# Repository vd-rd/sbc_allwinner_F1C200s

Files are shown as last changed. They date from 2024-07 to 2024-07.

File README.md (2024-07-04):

# Allwinner F1C200s SBC

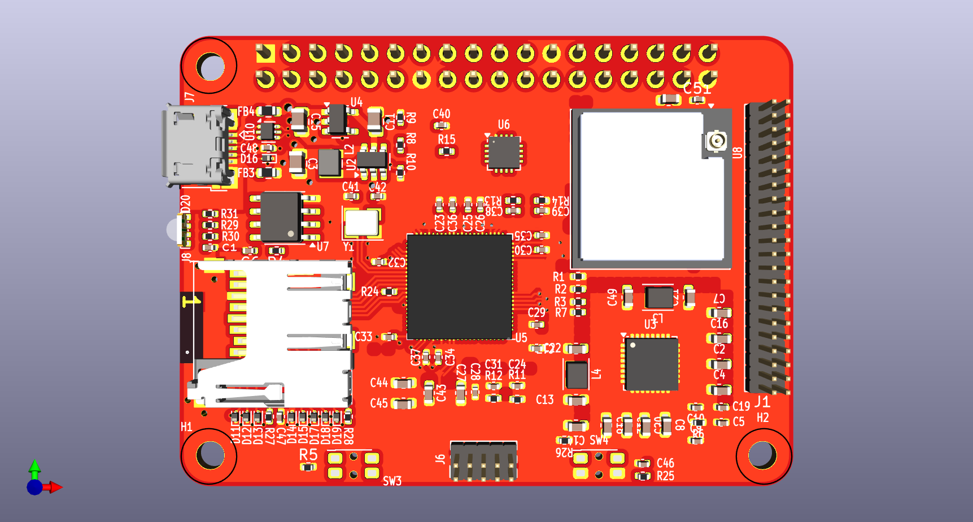
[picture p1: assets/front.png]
board_render


This board embeds a SIP (single core 533MHz ARM926EJ-S with 64MB DDR) with AXP173 PMIC, IO headers and microSD/eMMC storage. The board is also compatible with the smaller F1C100s that only embedds 32MB DDR RAM.

Note: The uC has two SDIO controllers (SDIO0 - 4bit wide, SDIO1 - 1bit wide). SDIO0 is used for SDCard. To provide wireless networking, while not sacrificing a large amount of pins, a design decision was made to use ESP32 module to provide WiFi/BT capabilities connected via SPI bus, leveraging [ESP_HOSTED_NG](https://github.com/espressif/esp-hosted) as a solution.
## Board overview (draft):

[TBD]

## Board features

| Characteristic | Description |
| --- | --- |
| Dimensions | 60mm x 40mm |
| Processor | Allwinner F1C100s/F1C200s ARM926EJ-S @533MHz |
| Oscillators | 24MHz main clock |
| RAM | 32/64MB embedded DDR memory |
| Storage | microSD/eMMC |
| USB | 1 microUSB OTG |
| Supply | Power path between USB/Vin/Battery, 5V max |

## Notes and observations
[TBD]

## Resources
 - online viewer for schematic/layout (https://cadlab.io/project/23988).

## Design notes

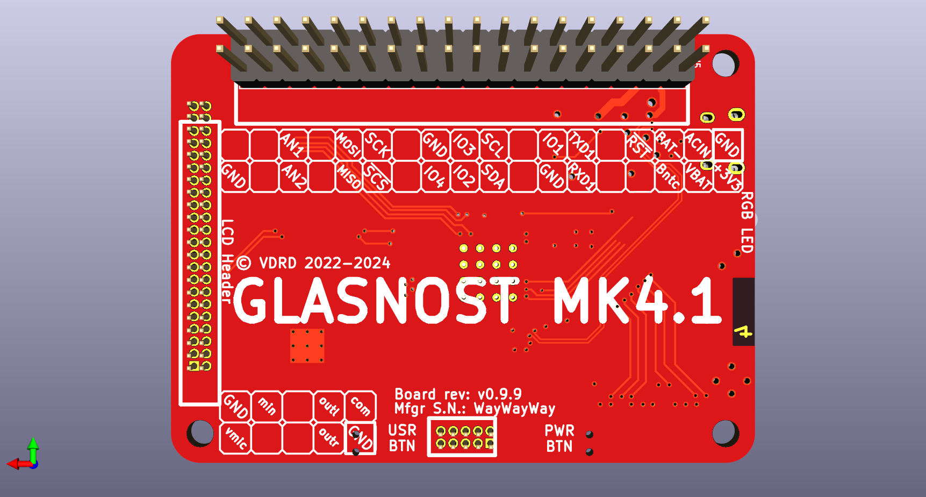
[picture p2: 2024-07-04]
assets/back.png

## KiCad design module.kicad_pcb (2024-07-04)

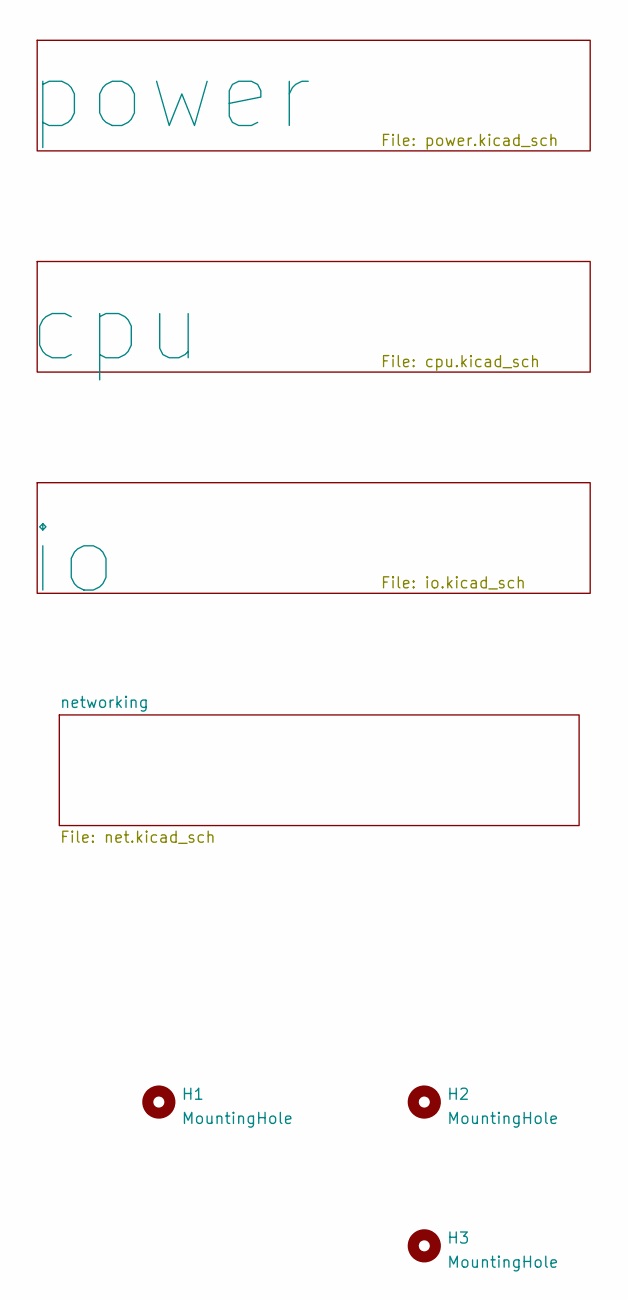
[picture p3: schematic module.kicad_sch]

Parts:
H1, H2, H3: MountingHole; MountingHole_2.7mm_M2.5

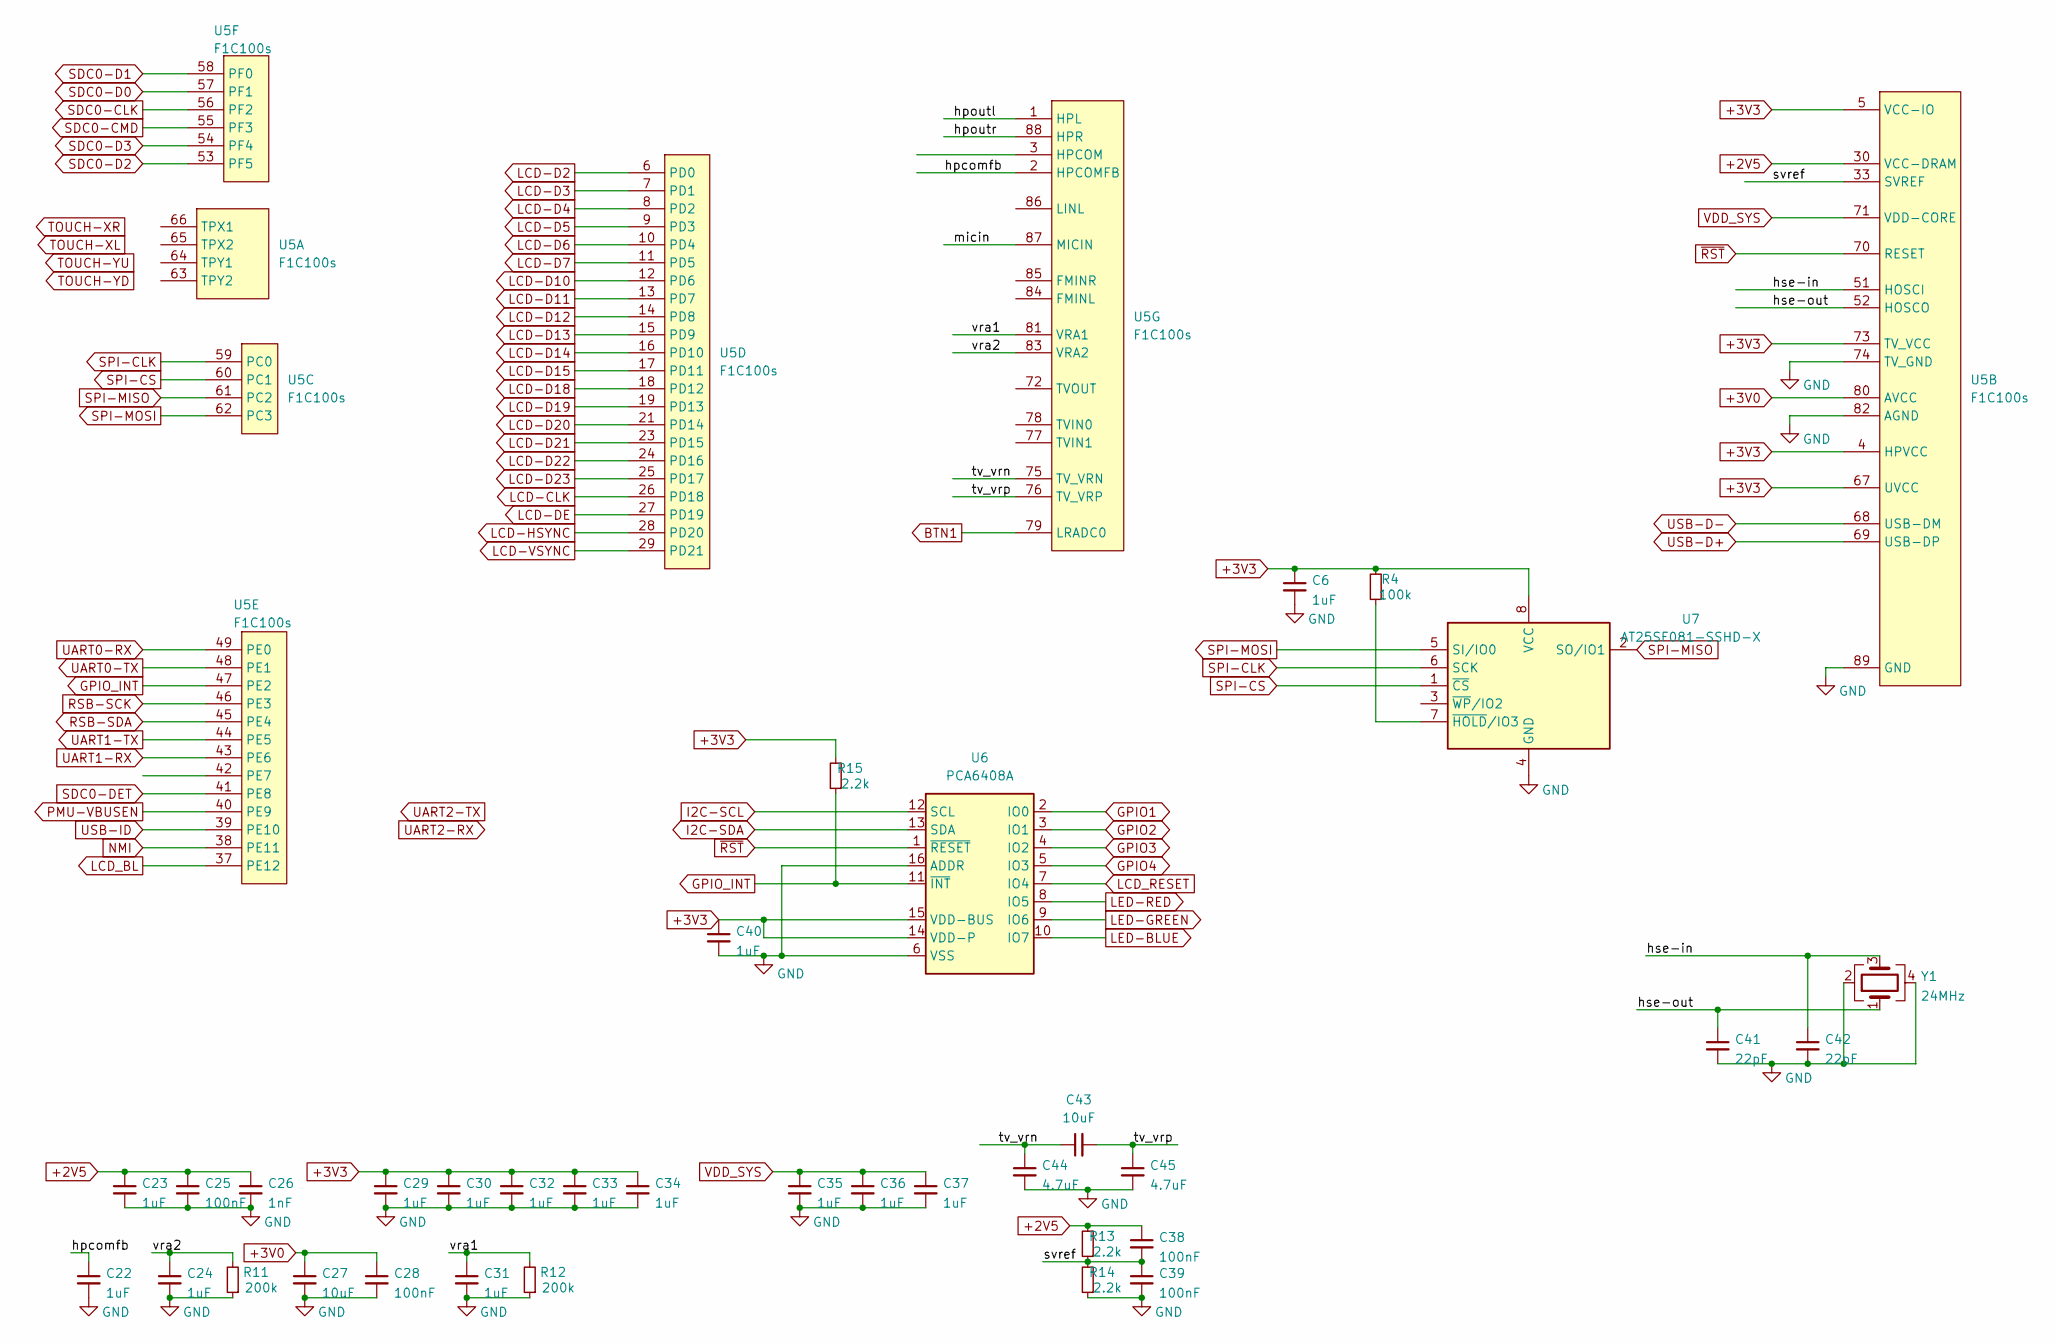
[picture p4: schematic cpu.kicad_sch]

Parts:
C6, C22, C23, C24, C29, C30, C31, C32, C33, C34, C35, C36, C37, C40: 1uF; C_0402_1005Metric
C25, C28, C38, C39: 100nF; C_0402_1005Metric
C26: 1nF; C_0402_1005Metric
C27, C43: 10uF; C_0603_1608Metric
C41, C42: 22pF; C_0402_1005Metric
C44, C45: 4.7uF; C_0603_1608Metric
R4: 100k; R_0402_1005Metric
R11, R12: 200k; R_0402_1005Metric
R13, R14, R15: 2.2k; R_0402_1005Metric
U5: F1C100s; QFN-88_EP_10x10_Pitch0.4mm
U6: PCA6408A; QFN-16-1EP_3x3mm_P0.5mm_EP1.7x1.7mm
U7: AT25SF081-SSHD-X; SOIC-8_3.9x4.9mm_P1.27mm
Y1: 24MHz; Crystal_SMD_3225-4Pin_3.2x2.5mm

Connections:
+2V5: C23.1, C25.1, C26.1, C38.1, R13.2, U5.30 (VCC-DRAM), U5.31 (VCC-DRAM), U5.32 (VCC-DRAM), U5.34 (VCC-DRAM), U5.36 (VCC-DRAM); also elsewhere on the board
+3V0: C27.1, C28.1, U5.80 (AVCC); also elsewhere on the board
+3V3: C6.1, C29.1, C30.1, C32.1, C33.1, C34.1, C40.1, R4.2, R15.2, U5.4 (HPVCC), U5.5 (VCC-IO), U5.20 (VCC-IO), U5.50 (VCC-IO), U5.67 (UVCC), U5.73 (TV_VCC), U6.14 (VDD-P), U6.15 (VDD-BUS), U7.8 (VCC); also elsewhere on the board
/cpu/hpcomfb: C22.1, U5.2 (HPCOMFB)
/cpu/hpoutl: U5.1 (HPL)
/cpu/hpoutr: U5.88 (HPR)
/cpu/hse-in: C42.1, U5.51 (HOSCI), Y1.3
/cpu/hse-out: C41.1, U5.52 (HOSCO), Y1.1
/cpu/micin: U5.87 (MICIN)
/cpu/svref: C38.2, C39.1, R13.1, R14.2, U5.33 (SVREF)
/cpu/tv_vrn: C43.1, C44.1, U5.75 (TV_VRN)
/cpu/tv_vrp: C43.2, C45.1, U5.76 (TV_VRP)
/cpu/vra1: C31.1, R12.2, U5.81 (VRA1)
/cpu/vra2: C24.1, R11.2, U5.83 (VRA2)
BTN1: U5.79 (LRADC0); also elsewhere on the board
GND: C6.2, C22.2, C23.2, C24.2, C25.2, C26.2, C27.2, C28.2, C29.2, C30.2, C31.2, C32.2, C33.2, C34.2, C35.2, C36.2, C37.2, C39.2, C40.2, C41.2, C42.2, C44.2, C45.2, R11.1, R12.1, R14.1, U5.74 (TV_GND), U5.82 (AGND), U5.89 (GND), U6.6 (VSS), U6.16 (ADDR), U7.4 (GND), Y1.2, Y1.4; also elsewhere on the board
GPIO1: U6.2 (IO0); also elsewhere on the board
GPIO2: U6.3 (IO1); also elsewhere on the board
GPIO3: U6.4 (IO2); also elsewhere on the board
GPIO4: U6.5 (IO3); also elsewhere on the board
GPIO_INT: R15.1, U5.47 (PE2), U6.11 (~INT)
I2C-SCL: U6.12 (SCL); also elsewhere on the board
I2C-SDA: U6.13 (SDA); also elsewhere on the board
LCD-CLK: U5.26 (PD18); also elsewhere on the board
LCD-D2: U5.6 (PD0); also elsewhere on the board
LCD-D3: U5.7 (PD1); also elsewhere on the board
LCD-D4: U5.8 (PD2); also elsewhere on the board
LCD-D5: U5.9 (PD3); also elsewhere on the board
LCD-D6: U5.10 (PD4); also elsewhere on the board
LCD-D7: U5.11 (PD5); also elsewhere on the board
LCD-D10: U5.12 (PD6); also elsewhere on the board
LCD-D11: U5.13 (PD7); also elsewhere on the board
LCD-D12: U5.14 (PD8); also elsewhere on the board
LCD-D13: U5.15 (PD9); also elsewhere on the board
LCD-D14: U5.16 (PD10); also elsewhere on the board
LCD-D15: U5.17 (PD11); also elsewhere on the board
LCD-D18: U5.18 (PD12); also elsewhere on the board
LCD-D19: U5.19 (PD13); also elsewhere on the board
LCD-D20: U5.21 (PD14); also elsewhere on the board
LCD-D21: U5.23 (PD15); also elsewhere on the board
LCD-D22: U5.24 (PD16); also elsewhere on the board
LCD-D23: U5.25 (PD17); also elsewhere on the board
LCD-DE: U5.27 (PD19); also elsewhere on the board
LCD-HSYNC: U5.28 (PD20); also elsewhere on the board
LCD-VSYNC: U5.29 (PD21); also elsewhere on the board
LCD_BL: U5.37 (PE12); also elsewhere on the board
LCD_RESET: U6.7 (IO4); also elsewhere on the board
LED-BLUE: U6.10 (IO7); also elsewhere on the board
LED-GREEN: U6.9 (IO6); also elsewhere on the board
LED-RED: U6.8 (IO5); also elsewhere on the board
NMI: U5.38 (PE11); also elsewhere on the board
unnamed: R4.1, U7.7 (~HOLD/IO3)
PMU-VBUSEN: U5.40 (PE9); also elsewhere on the board
RSB-SCK: U5.46 (PE3); also elsewhere on the board
RSB-SDA: U5.45 (PE4); also elsewhere on the board
SDC0-CLK: U5.56 (PF2); also elsewhere on the board
SDC0-CMD: U5.55 (PF3); also elsewhere on the board
SDC0-D0: U5.57 (PF1); also elsewhere on the board
SDC0-D1: U5.58 (PF0); also elsewhere on the board
SDC0-D2: U5.53 (PF5); also elsewhere on the board
SDC0-D3: U5.54 (PF4); also elsewhere on the board
SDC0-DET: U5.41 (PE8); also elsewhere on the board
SPI-CLK: U5.59 (PC0), U7.6 (SCK); also elsewhere on the board
SPI-CS: U5.60 (PC1), U7.1 (~CS); also elsewhere on the board
SPI-MISO: U5.61 (PC2), U7.2 (SO/IO1); also elsewhere on the board
SPI-MOSI: U5.62 (PC3), U7.5 (SI/IO0); also elsewhere on the board
UART0-RX: U5.49 (PE0); also elsewhere on the board
UART0-TX: U5.48 (PE1); also elsewhere on the board
UART1-RX: U5.43 (PE6); also elsewhere on the board
UART1-TX: U5.44 (PE5); also elsewhere on the board
USB-D+: U5.69 (USB-DP); also elsewhere on the board
USB-D-: U5.68 (USB-DM); also elsewhere on the board
USB-ID: U5.39 (PE10); also elsewhere on the board
VDD_SYS: C35.1, C36.1, C37.1, U5.22 (VDD-CORE), U5.35 (VDD-CORE), U5.71 (VDD-CORE); also elsewhere on the board
~RST: U5.70 (RESET), U6.1 (~RESET); also elsewhere on the board

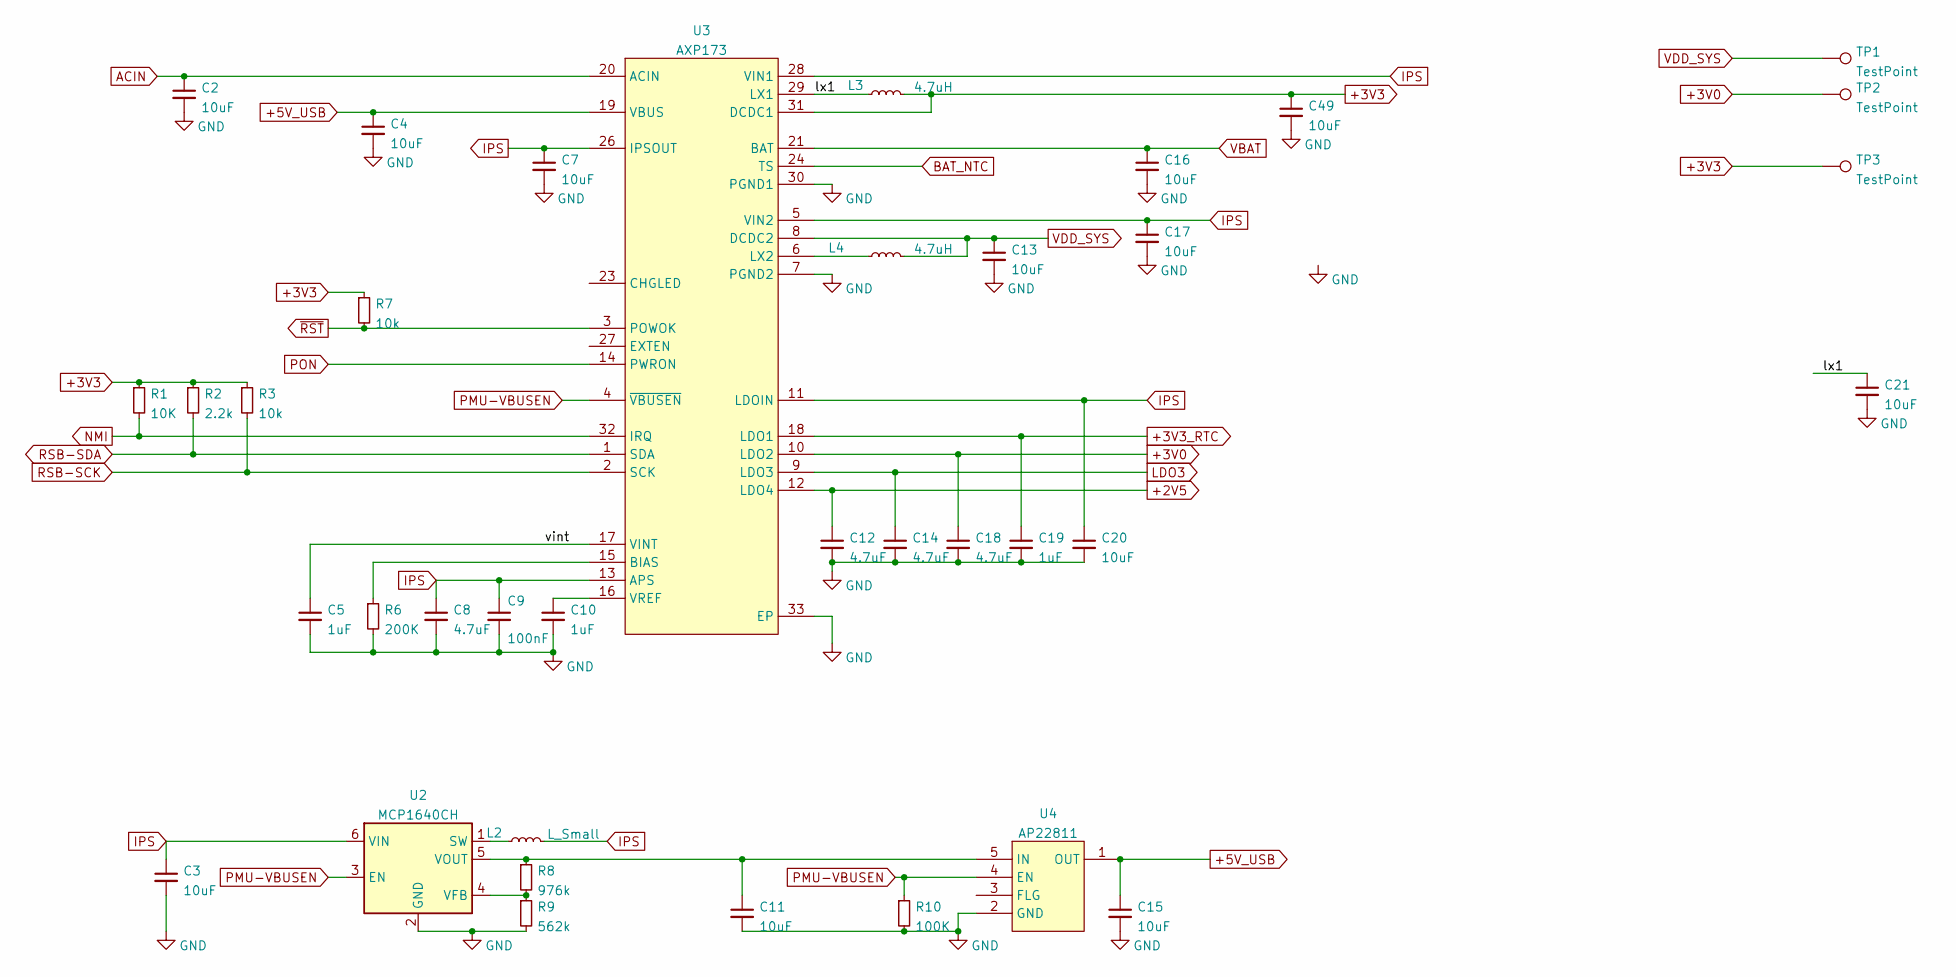
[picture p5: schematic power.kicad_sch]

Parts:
C2, C4, C7, C13, C16, C17, C20, C21, C49: 10uF; C_0603_1608Metric
C3, C11, C15: 10uF; C_0805_2012Metric
C5, C10, C19: 1uF; C_0402_1005Metric
C8, C12, C14, C18: 4.7uF; C_0603_1608Metric
C9: 100nF; C_0402_1005Metric
L2: L_Small; L_Wuerth_MAPI-2510
L3, L4: 4.7uH; L_Sunlord_SWPA252010S
R1: 10K; R_0402_1005Metric
R2: 2.2k; R_0402_1005Metric
R3, R7: 10k; R_0402_1005Metric
R6: 200K; R_0402_1005Metric
R8: 976k; R_0402_1005Metric
R9: 562k; R_0402_1005Metric
R10: 100K; R_0402_1005Metric
TP1, TP2, TP3: TestPoint; TestPoint_Pad_D1.0mm
U2: MCP1640CH; SOT-23-6
U3: AXP173; VQFN-32-1EP_5x5mm_P0.5mm_EP3.5x3.5mm_ThermalVias
U4: AP22811; SOT-23-5

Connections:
+2V5: C12.1, U3.12 (LDO4); also elsewhere on the board
+3V0: C18.1, TP2.1, U3.10 (LDO2); also elsewhere on the board
+3V3: C49.1, L3.2, R1.1, R2.1, R3.1, R7.1, TP3.1, U3.31 (DCDC1); also elsewhere on the board
+3V3_RTC: C19.1, U3.18 (LDO1)
+5V_USB: C4.1, C15.1, U3.19 (VBUS), U4.1 (OUT); also elsewhere on the board
/power/lx1: C21.1, L3.1, U3.29 (LX1)
/power/vint: C5.1, U3.17 (VINT)
ACIN: C2.1, U3.20 (ACIN); also elsewhere on the board
BAT_NTC: U3.24 (TS); also elsewhere on the board
GND: C2.2, C3.2, C4.2, C5.2, C7.2, C8.2, C9.2, C10.2, C11.2, C12.2, C13.2, C14.2, C15.2, C16.2, C17.2, C18.2, C19.2, C20.2, C21.2, C49.2, R6.2, R9.2, R10.2, U2.2 (GND), U3.7 (PGND2), U3.30 (PGND1), U3.33 (EP), U4.2 (GND); also elsewhere on the board
IPS: C3.1, C7.1, C8.1, C9.1, C17.1, C20.1, L2.2, U2.6 (VIN), U3.5 (VIN2), U3.11 (LDOIN), U3.13 (APS), U3.25 (IPSOUT), U3.26 (IPSOUT), U3.28 (VIN1)
LDO3: C14.1, U3.9 (LDO3); also elsewhere on the board
NMI: R1.2, U3.32 (IRQ); also elsewhere on the board
unnamed: L2.1, U2.1 (SW)
unnamed: R8.2, R9.1, U2.4 (VFB)
unnamed: C11.1, R8.1, U2.5 (VOUT), U4.5 (IN)
unnamed: R6.1, U3.15 (BIAS)
unnamed: L4.1, U3.6 (LX2)
unnamed: C10.1, U3.16 (VREF)
PMU-VBUSEN: R10.1, U2.3 (EN), U3.4 (~VBUSEN), U4.4 (EN); also elsewhere on the board
PON: U3.14 (PWRON); also elsewhere on the board
RSB-SCK: R3.2, U3.2 (SCK); also elsewhere on the board
RSB-SDA: R2.2, U3.1 (SDA); also elsewhere on the board
VBAT: C16.1, U3.21 (BAT), U3.22 (BAT); also elsewhere on the board
VDD_SYS: C13.1, L4.2, TP1.1, U3.8 (DCDC2); also elsewhere on the board
~RST: R7.2, U3.3 (POWOK); also elsewhere on the board

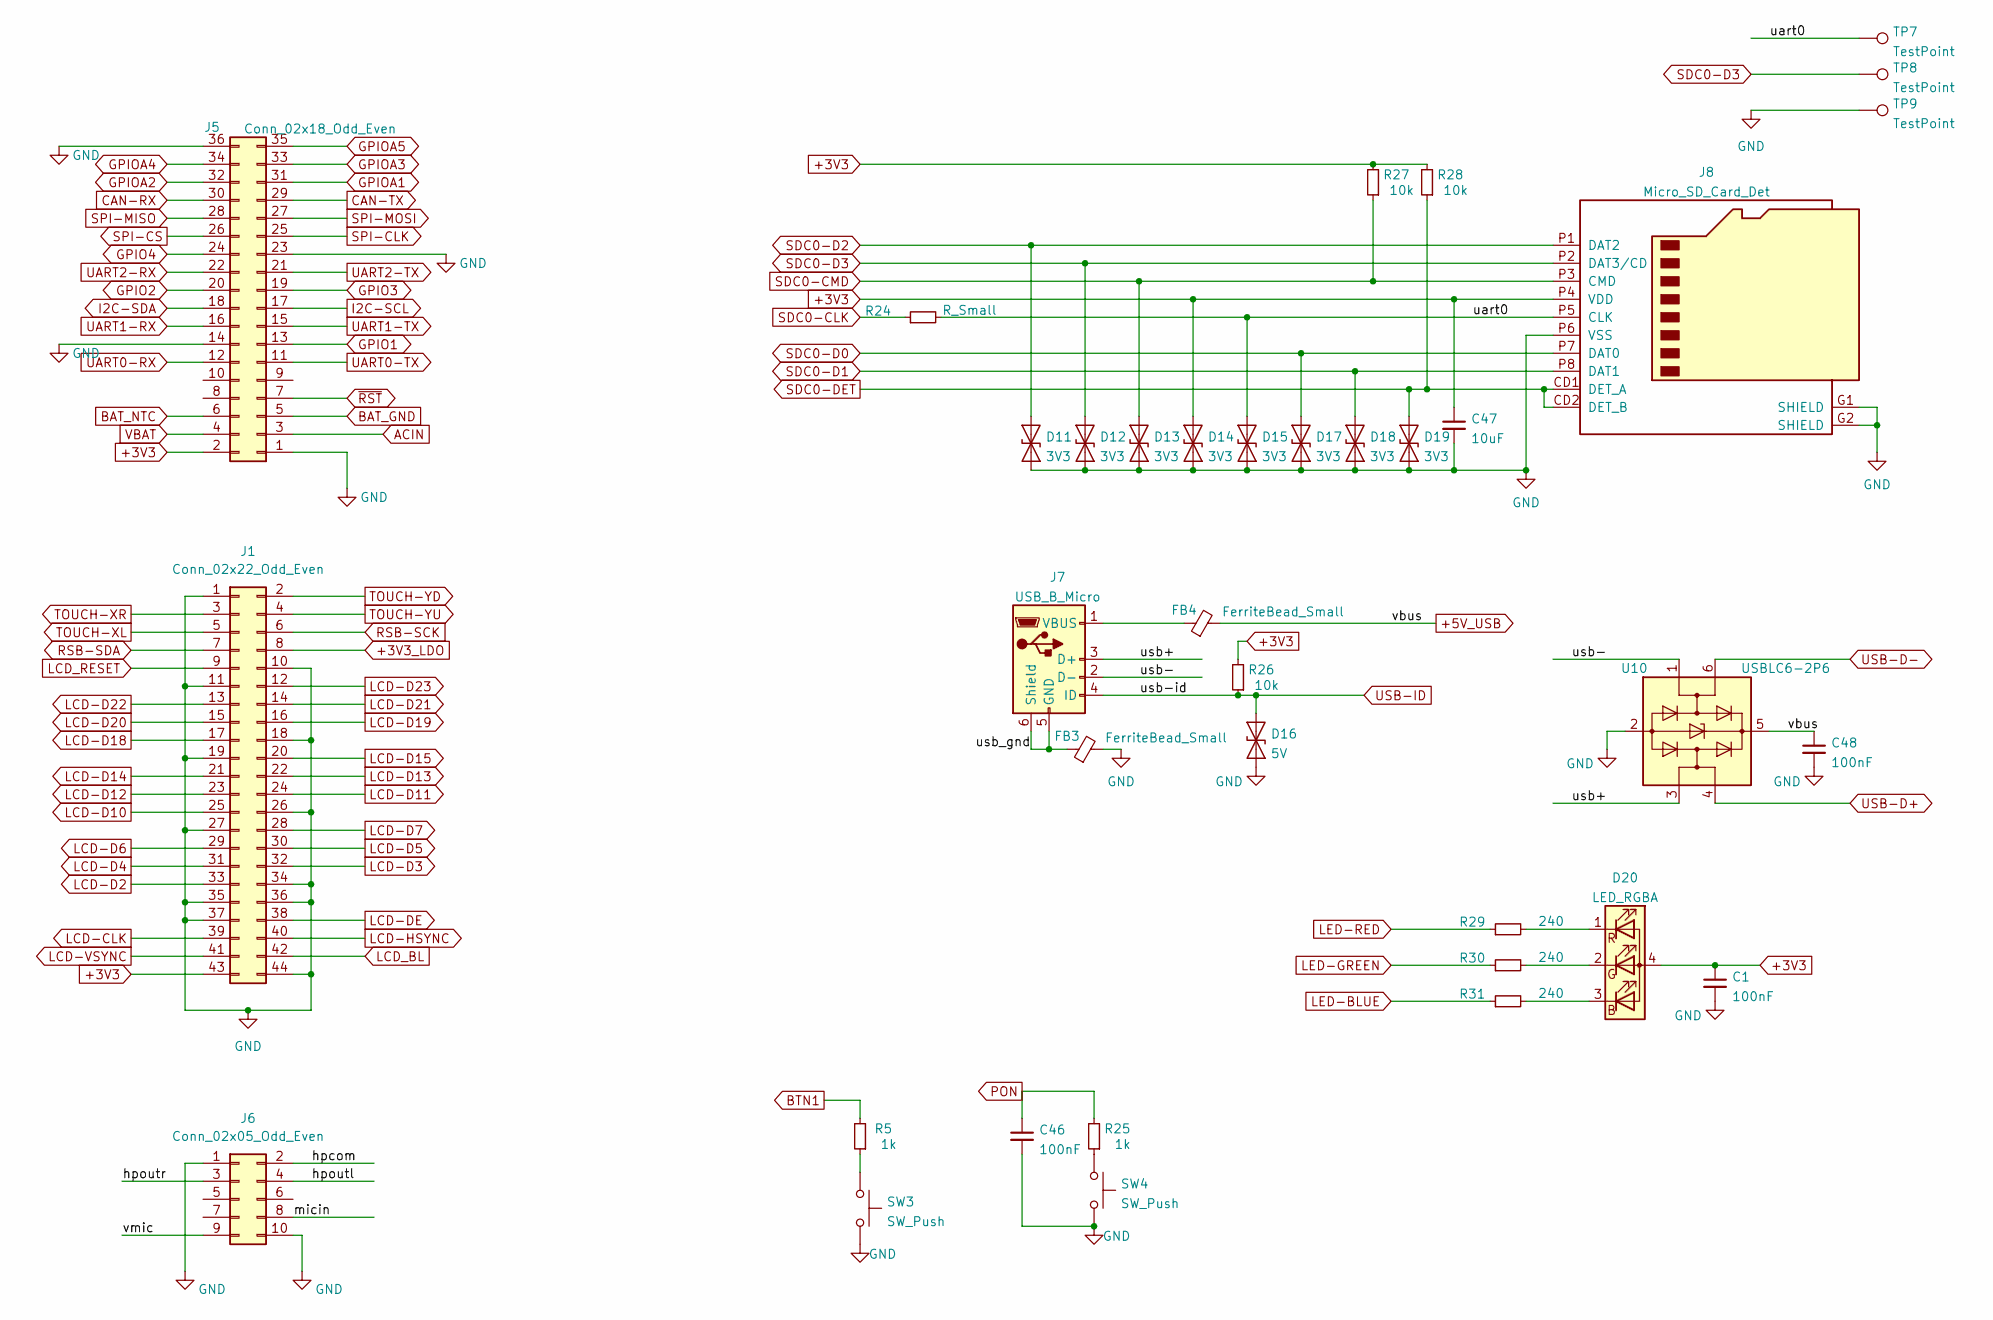
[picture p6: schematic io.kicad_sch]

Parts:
C1, C46, C48: 100nF; C_0402_1005Metric
C47: 10uF; C_0402_1005Metric
D11, D12, D13, D14, D15, D17, D18, D19: 3V3; D_SOD-923
D16: 5V; D_SOD-923
D20: LED_RGBA; rgb-1204
FB3, FB4: FerriteBead_Small; R_0603_1608Metric
J1: Conn_02x22_Odd_Even; PinHeader_2x22_P1.27mm_Vertical
J5: Conn_02x18_Odd_Even; PinHeader_2x18_P2.54mm_Vertical
J6: Conn_02x05_Odd_Even; PinHeader_2x05_P1.27mm_Vertical
J7: USB_B_Micro; USB_Micro-B_Amphenol_10103594-0001LF_Horizontal
J8: Micro_SD_Card_Det; MEM20610118800A
R5, R25: 1k; R_0402_1005Metric
R24: R_Small; R_0402_1005Metric
R26, R27, R28: 10k; R_0402_1005Metric
R29, R30, R31: 240; R_0402_1005Metric
SW3, SW4: SW_Push; SW_SPST_EVQP7C
TP7, TP8, TP9: TestPoint; TestPoint_Pad_D1.0mm
U10: USBLC6-2P6; SOT-666

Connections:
+3V3: C1.1, C47.1, D14.2 (A2), D20.4 (A), J1.43, J5.2, J8.P4 (VDD), R26.2, R27.2, R28.2; also elsewhere on the board
+3V3_LDO: J1.8
+5V_USB: C48.1, FB4.2, U10.5 (VBUS); also elsewhere on the board
/io/hpcom: J6.2
/io/hpoutl: J6.4
/io/hpoutr: J6.3
/io/micin: J6.8
/io/uart0: D15.2 (A2), J8.P5 (CLK), R24.2, TP7.1
/io/usb+: J7.3 (D+), U10.3 (I/O2)
/io/usb-: J7.2 (D-), U10.1 (I/O1)
/io/usb_gnd: FB3.1, J7.5 (GND), J7.6 (Shield)
/io/vmic: J6.9
ACIN: J5.3; also elsewhere on the board
BAT_GND: J5.5
BAT_NTC: J5.6; also elsewhere on the board
BTN1: R5.2; also elsewhere on the board
CAN-RX: J5.30
CAN-TX: J5.29
GND: C1.2, C46.2, C47.2, C48.2, D11.1 (A1), D12.1 (A1), D13.1 (A1), D14.1 (A1), D15.1 (A1), D16.1 (A1), D17.1 (A1), D18.1 (A1), D19.1 (A1), FB3.2, J1.1, J1.10, J1.11, J1.18, J1.19, J1.26, J1.27, J1.34, J1.35, J1.36, J1.37, J1.44, J5.1, J5.14, J5.23, J5.36, J6.1, J6.10, J8.G1 (SHIELD), J8.G2 (SHIELD), J8.P6 (VSS), SW3.2, SW4.2, TP9.1, U10.2 (GND); also elsewhere on the board
GPIO1: J5.13; also elsewhere on the board
GPIO2: J5.20; also elsewhere on the board
GPIO3: J5.19; also elsewhere on the board
GPIO4: J5.24; also elsewhere on the board
GPIOA1: J5.31
GPIOA2: J5.32
GPIOA3: J5.33
GPIOA4: J5.34
GPIOA5: J5.35
I2C-SCL: J5.17; also elsewhere on the board
I2C-SDA: J5.18; also elsewhere on the board
LCD-CLK: J1.39; also elsewhere on the board
LCD-D2: J1.33; also elsewhere on the board
LCD-D3: J1.32; also elsewhere on the board
LCD-D4: J1.31; also elsewhere on the board
LCD-D5: J1.30; also elsewhere on the board
LCD-D6: J1.29; also elsewhere on the board
LCD-D7: J1.28; also elsewhere on the board
LCD-D10: J1.25; also elsewhere on the board
LCD-D11: J1.24; also elsewhere on the board
LCD-D12: J1.23; also elsewhere on the board
LCD-D13: J1.22; also elsewhere on the board
LCD-D14: J1.21; also elsewhere on the board
LCD-D15: J1.20; also elsewhere on the board
LCD-D18: J1.17; also elsewhere on the board
LCD-D19: J1.16; also elsewhere on the board
LCD-D20: J1.15; also elsewhere on the board
LCD-D21: J1.14; also elsewhere on the board
LCD-D22: J1.13; also elsewhere on the board
LCD-D23: J1.12; also elsewhere on the board
LCD-DE: J1.38; also elsewhere on the board
LCD-HSYNC: J1.40; also elsewhere on the board
LCD-VSYNC: J1.41; also elsewhere on the board
LCD_BL: J1.42; also elsewhere on the board
LCD_RESET: J1.9; also elsewhere on the board
LED-BLUE: R31.1; also elsewhere on the board
LED-GREEN: R30.1; also elsewhere on the board
LED-RED: R29.1; also elsewhere on the board
unnamed: D20.3 (BK), R31.2
unnamed: D20.2 (GK), R30.2
unnamed: D20.1 (RK), R29.2
unnamed: FB4.1, J7.1 (VBUS)
unnamed: R5.1, SW3.1
unnamed: R25.1, SW4.1
PON: C46.1, R25.2; also elsewhere on the board
RSB-SCK: J1.6; also elsewhere on the board
RSB-SDA: J1.7; also elsewhere on the board
SDC0-CLK: R24.1; also elsewhere on the board
SDC0-CMD: D13.2 (A2), J8.P3 (CMD), R27.1; also elsewhere on the board
SDC0-D0: D17.2 (A2), J8.P7 (DAT0); also elsewhere on the board
SDC0-D1: D18.2 (A2), J8.P8 (DAT1); also elsewhere on the board
SDC0-D2: D11.2 (A2), J8.P1 (DAT2); also elsewhere on the board
SDC0-D3: D12.2 (A2), J8.P2 (DAT3/CD), TP8.1; also elsewhere on the board
SDC0-DET: D19.2 (A2), J8.CD1 (DET_A), J8.CD2 (DET_B), R28.1; also elsewhere on the board
SPI-CLK: J5.25; also elsewhere on the board
SPI-CS: J5.26; also elsewhere on the board
SPI-MISO: J5.28; also elsewhere on the board
SPI-MOSI: J5.27; also elsewhere on the board
TOUCH-XL: J1.5
TOUCH-XR: J1.3
TOUCH-YD: J1.2
TOUCH-YU: J1.4
UART0-RX: J5.12; also elsewhere on the board
UART0-TX: J5.11; also elsewhere on the board
UART1-RX: J5.16; also elsewhere on the board
UART1-TX: J5.15; also elsewhere on the board
UART2-RX: J5.22
UART2-TX: J5.21
USB-D+: U10.4 (I/O2); also elsewhere on the board
USB-D-: U10.6 (I/O1); also elsewhere on the board
USB-ID: D16.2 (A2), J7.4 (ID), R26.1; also elsewhere on the board
VBAT: J5.4; also elsewhere on the board
~RST: J5.7; also elsewhere on the board

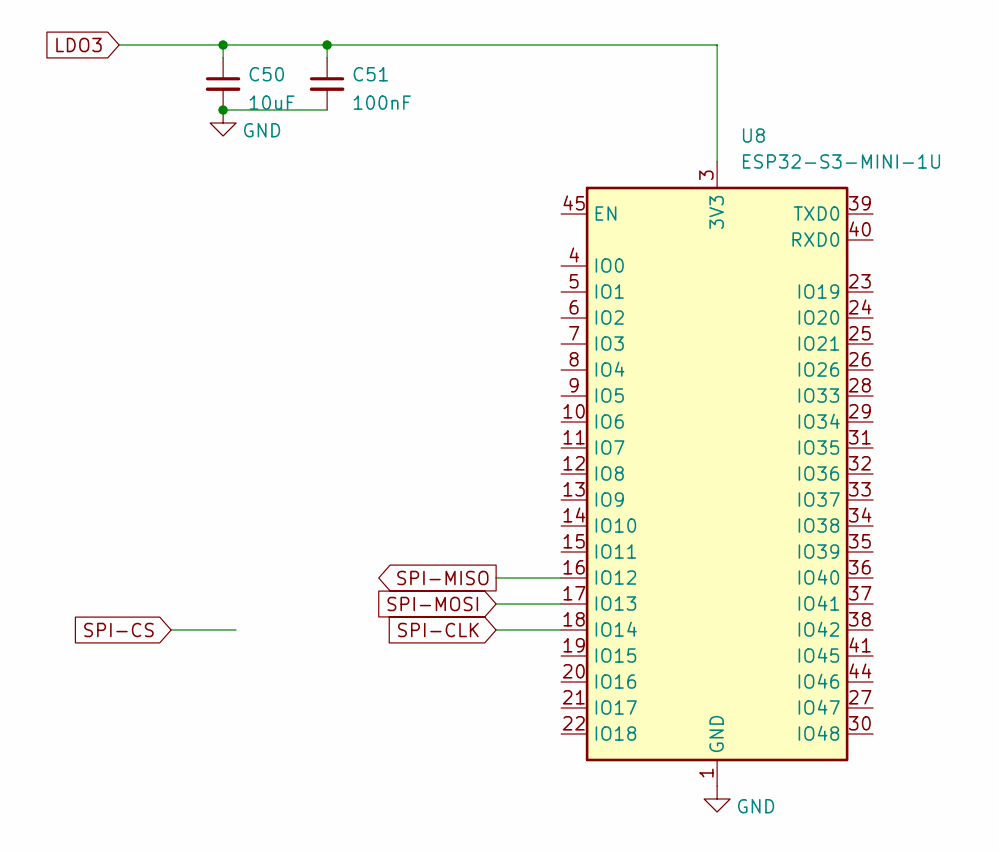
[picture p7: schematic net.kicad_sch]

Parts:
C50: 10uF; C_0603_1608Metric
C51: 100nF; C_0402_1005Metric
U8: ESP32-S3-MINI-1U; ESP32-S2-MINI-1U

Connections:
GND: C50.2, C51.2, U8.1 (GND), U8.2 (GND), U8.42 (GND), U8.43 (GND), U8.46 (GND), U8.47 (GND), U8.48 (GND), U8.49 (GND), U8.50 (GND), U8.51 (GND), U8.52 (GND), U8.53 (GND), U8.54 (GND), U8.55 (GND), U8.56 (GND), U8.57 (GND), U8.58 (GND), U8.59 (GND), U8.60 (GND), U8.61 (GND), U8.62 (GND), U8.63 (GND), U8.64 (GND), U8.65 (GND); also elsewhere on the board
LDO3: C50.1, C51.1, U8.3 (3V3); also elsewhere on the board
SPI-CLK: U8.18 (IO14); also elsewhere on the board
SPI-MISO: U8.16 (IO12); also elsewhere on the board
SPI-MOSI: U8.17 (IO13); also elsewhere on the board

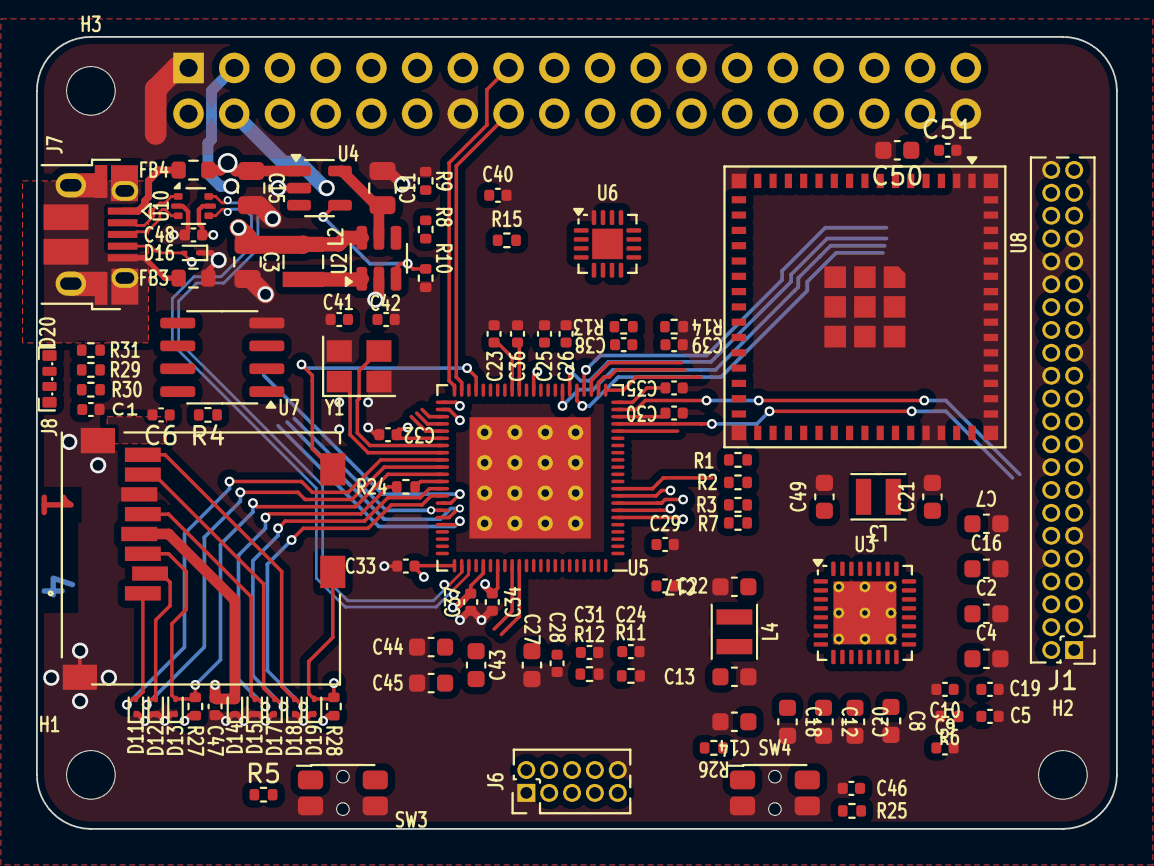
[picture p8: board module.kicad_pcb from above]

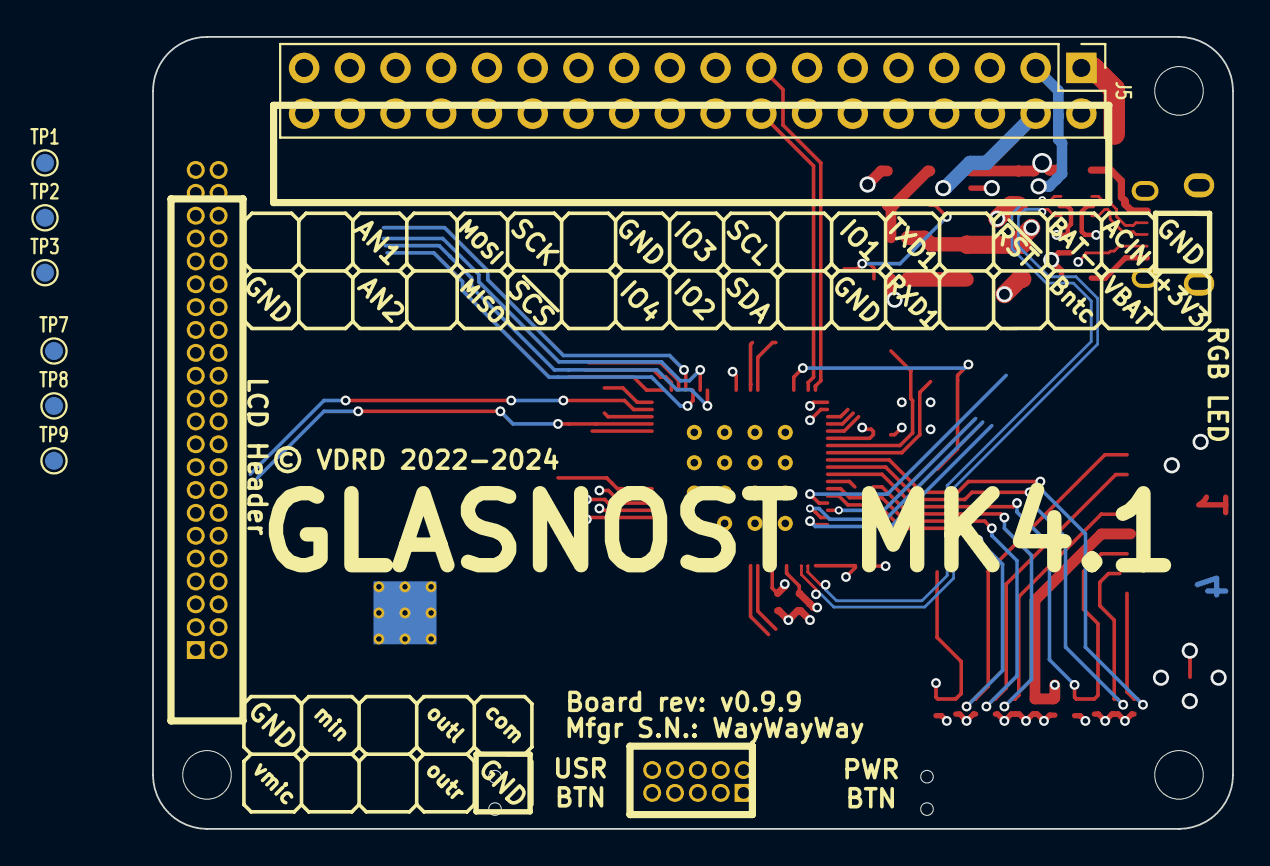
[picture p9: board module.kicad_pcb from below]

Board: 4 copper layers, 60.0 x 44.0 mm, 114 parts (7 on the bottom side), 98 nets.

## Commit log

2021-03-06 first kicad project
    [module.kicad_pcb, module.sch]
2021-03-07 add pmic schematic
    [module.kicad_pcb, module.sch, power.sch]
2021-03-07 add io and cpu
    [IO.sch, cpu.sch, module.kicad_pcb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]
2021-03-07 add io connectors
    [IO.sch, module.kicad_pcb]
2021-03-07 board improvements
    [IO.sch]
2021-03-08 define connections
    [IO.sch, cpu.sch, module.kicad_pcb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]
2021-03-10 define component placing
    [IO.sch, cpu.sch, module.kicad_pcb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]
2021-03-10 define IO connections
    [IO.sch, cpu.sch, module.kicad_pcb]
2021-03-11 redefine connections
    [IO.sch, cpu.sch, module.kicad_pcb]
2021-06-13 updated project
    [IO.sch, cpu.sch, module.kicad_pcb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]
2021-09-02 project restructure
    [IO.kicad_sch, IO.sch, cpu.kicad_sch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]
2021-10-04 project cleanup
    [IO.kicad_sch, IO.sch, cpu.kicad_sch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]
2021-10-04 improve floorplan and change pmic to axp173
    [cpu.kicad_sch, io.kicad_sch, module.kicad_pcb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]
2021-10-04 add 3v3 rail
    [module.kicad_pcb, module.kicad_sch, power.kicad_sch]
2021-10-04 revert to two layer design
    [cpu.kicad_sch, io.kicad_sch, module.kicad_pcb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]
2021-10-06 updates on features and layout
    [cpu.kicad_sch, module.kicad_pcb, module.kicad_sch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]
2021-10-09 add header pins
    [cpu.kicad_sch, io.kicad_sch, module.kicad_pcb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]
2021-10-10 routing for signals
    [module.kicad_pcb, power.kicad_sch]
2021-10-10 power stage routed
    [module.kicad_pcb]
2021-10-16 more routing
    [module.kicad_pcb]
2021-10-24 defined cpu signals
    [cpu.kicad_sch, io.kicad_sch, module.kicad_pcb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]
2021-10-25 added 3d models
    [module.kicad_pcb]
2021-10-26 more cosmetic fixes
    [cpu.kicad_sch, io.kicad_sch, module.kicad_pcb]
2022-01-16 add layer identification labels
    [cpu.kicad_sch, io.kicad_sch, module.kicad_pcb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]
2022-03-24 small udpates
    [module.kicad_pcb]
2022-04-16 add audio block
    [cpu.kicad_sch, module.kicad_pcb, module.kicad_sch]
2022-04-20 redesign board connections
    [cpu.kicad_sch, module.kicad_pcb, module.kicad_sch]
2022-05-07 add port expander
    [cpu.kicad_sch, module.kicad_pcb, module.kicad_sch]
2024-03-31 bump to kicad 8
    [cpu.kicad_sch, io.kicad_sch, module.kicad_pcb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]
2024-07-02 added wireless networking
    [cpu.kicad_sch, io.kicad_sch, module.kicad_pcb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]
2024-07-03 finished sdio bus for sd card
    [module.kicad_pcb]
2024-07-04 add wip render
    [cpu.kicad_sch, io.kicad_sch, module.kicad_pcb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]
2024-07-04 added silkscreen info
    [module.kicad_pcb]

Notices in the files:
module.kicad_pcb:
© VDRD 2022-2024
